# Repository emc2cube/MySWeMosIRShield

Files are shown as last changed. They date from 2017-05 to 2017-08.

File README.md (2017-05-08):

MySWeMosIRShield - IR blaster shield for WeMos D1 Mini with HTTP and MySensors support
==========

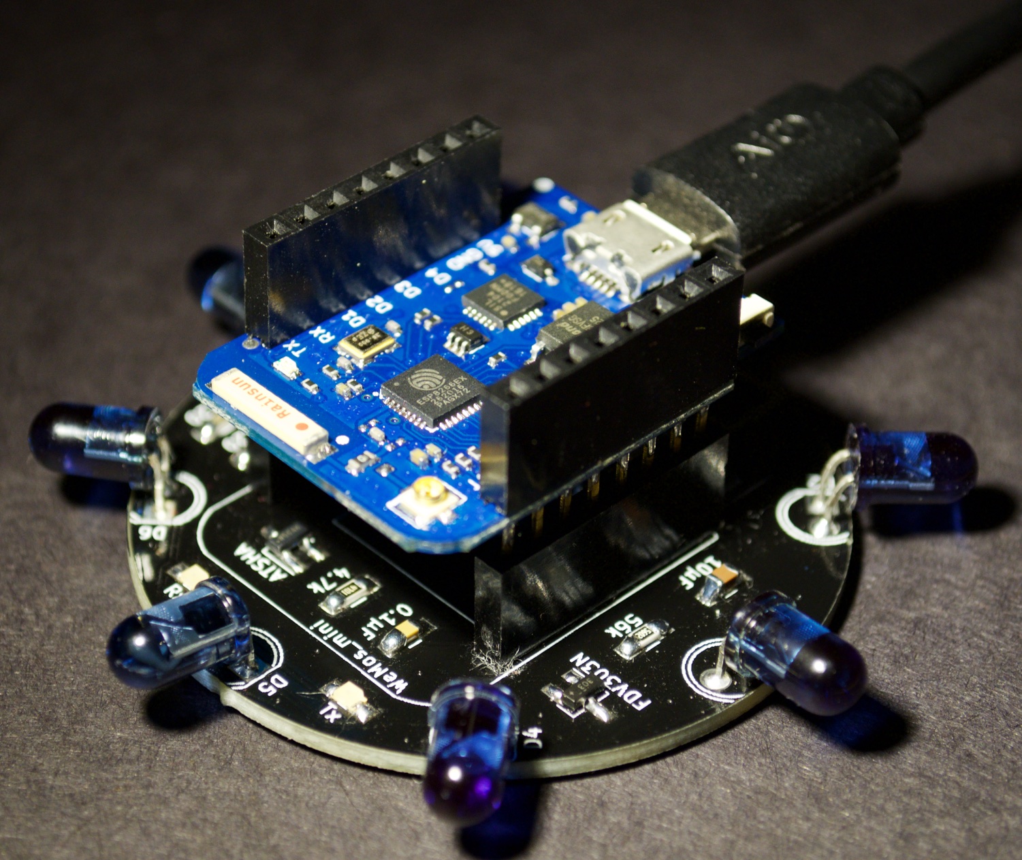
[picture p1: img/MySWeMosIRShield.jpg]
MySWeMosIRShield

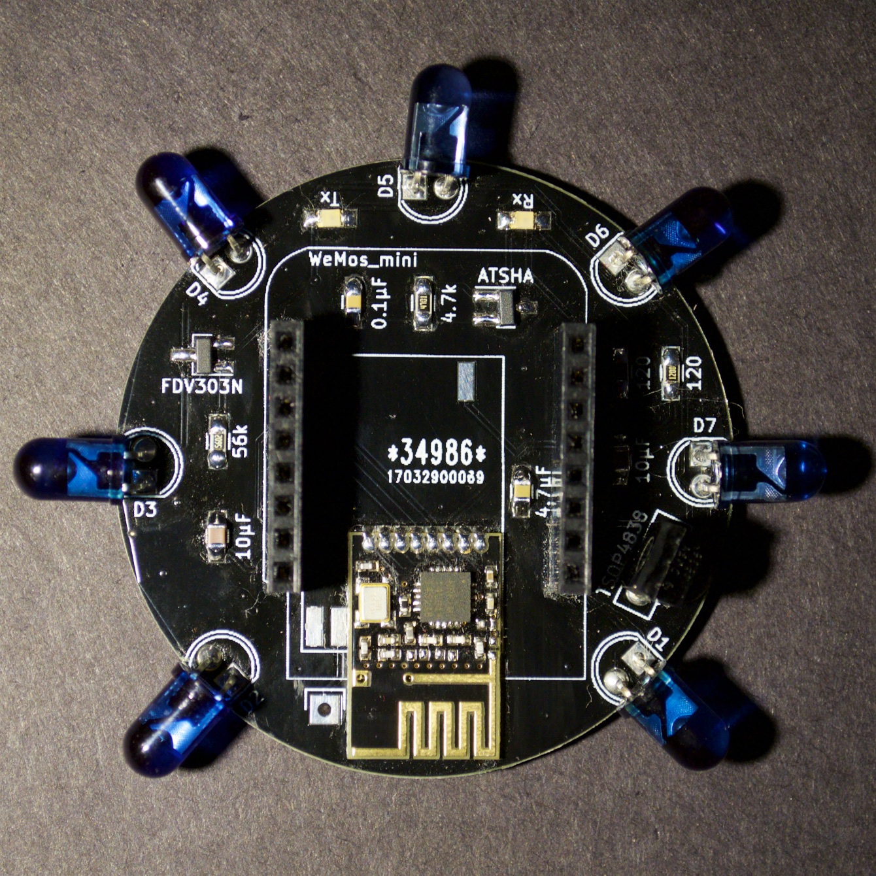
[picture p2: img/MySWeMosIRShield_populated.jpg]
MySWeMosIRShield populated board

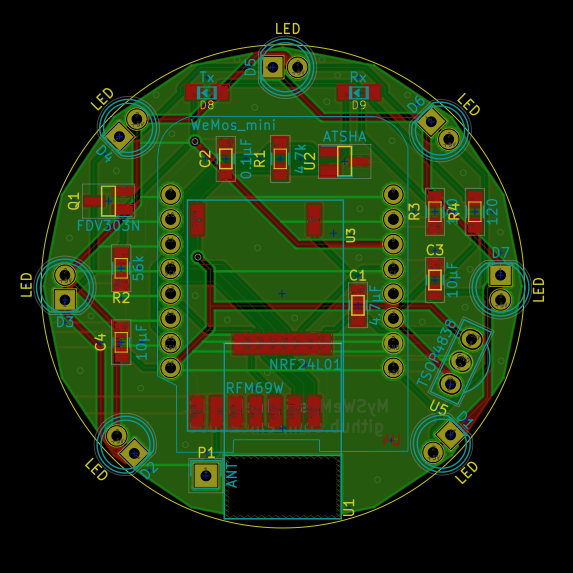
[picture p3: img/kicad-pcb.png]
KiCad view


Description
-----------

[MySensors](http://www.mysensors.org) [WeMos Mini](https://www.wemos.cc/product/d1-mini-pro.html) Infra-Red blaster and receiver shield with support for SMD NRF24L01+ or SMD RFM69(H)W radio modules.

Ordering
--------

Gerber files are included so you can order these PCB at your favorite PCB fab house and solder the few components yourself.
For an easy ordering process, you can directly order these PCB without having to do anything else:
- [PCBs.io](https://PCBs.io/share/zeBwV) 4 for $14.70, black 1.6mm PCB, ENIG finish, 2-3 weeks.
- [DirtyPCBs](http://dirtypcbs.com/store/designer/details/10880/3104/myswemosirshield) ~10 for $15.95, multiple colors and PCB thickness, HASL finish, 5-8 weeks.

Assembly
--------

Start by soldering all the SMD components, then proceed to WeMos header, IR LEDs and IR receiver.
By default, the BOM indicates TSAL6400 LEDs but you can use any high-power IR LEDs to have different beam angle or power according to your needs. I personally use a mix of TSAL6400, TSAL6200 and TSAL6100.
Some of the SMD 0805 capacitors are optional and could be skipped but I still recommended to solder all of them for optimal operation.

Optional components
-------------------

### Status LEDs
Tx and Rx LEDs are optional. Their only purpose is to indicate than an IR signal was either sent or received.
If you do not wish to add these status LEDs you can also skip both 120Ω SMD 0805 resistors.
By default, in the BOM Rx is green and Tx is yellow, but you can use different colors, update their corresponding current limiting resistor if needed.

### ATSHA204 module (unsupported?)
For security reasons, you can add a CryptAuthEE SHA256 chip. This will allow you to sign messages and will secure communications between the gateway and other nodes (this is not encryption, just signing).
If you decide to add the ATSHA204 chip you will need to add a 0.1µF SMD 0805 decoupling capacitor and 4.7kΩ SMD 0805 pull-up resistor.
Signing can also be done at the software level, without the chip if you decide to add this function later.
For complete reference see the detailed [MySensors Security & Signing guide](https://www.mysensors.org/about/signing)

### IR receiver (TSOP4838)
The Infra-Red module is optional, if you already know your IR codes or plan to learn them separately you can omit it.

### Radio module
Because this module is based on ESP8266 you do not necessary need to install a radio module.
- You can use it as an independent module, only using HTTP, internal timers or with any other program that do not need to communicate with a radio network.
- You can use it as a gateway, connecting your controller to the module by WiFi directly.

Installation
-------

Plug your [WeMos Mini](https://www.wemos.cc/product/d1-mini-pro.html) on top of the shield and power it through the micro USB port.
Do not forget to edit the various options of the [Arduino example code](https://github.com/emc2cube/MySWeMosIRShield/tree/master/Arduino/) before uploading it.

Arduino
-------

Included program

### MySWeMosIRShield-RoboVac_TV
Example code implementing custom web server and MySensors support.
You will (very probably) need to modify this code with your own IR codes and definitions.
This program was created to allow me to control my [Eufy RoboVac 11 robotic vacuum cleaner](http://amzn.to/2pbbndL) which unfortunately by default lack of any advanced scheduling options. By default, this vacuum cleaner will start its "auto" mode every day at the same hour, but can now be scheduled to operate only certain days, at different times, or even using different modes.

This program will set up a web server on your WeMos that you can access from any other device on your local network or by connecting directly to the ESP8266 hotspot (depending on WiFi settings) allowing you to trigger IR commands.
Interface is optimized for access through a smartphone, allowing you to use it as a smart remote.

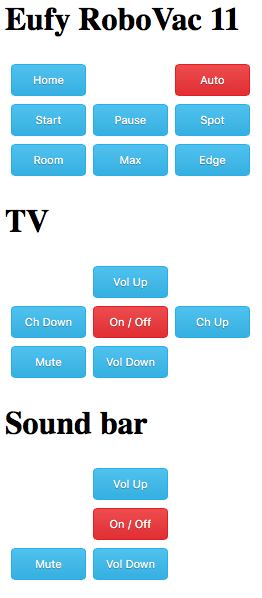
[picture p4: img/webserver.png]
WebServer


It will also create a [MySensors](http://www.mysensors.org) node behaving like a selector switch. You can then program it to perform various actions through your controller.

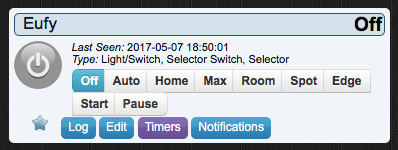
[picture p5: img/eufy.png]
Eufy


Revision history
----------------

Version 1.0: Initial release.

Special Kicad libraries
---------------

This project use the [Kicad footprints and templates for WeMos D1 mini board](https://github.com/jerome-labidurie/d1_mini_kicad) library.

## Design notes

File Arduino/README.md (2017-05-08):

MySWeMosIRShield - IR blaster shield for WeMos D1 Mini with HTTP and MySensors support
==========

Arduino
-------

Included program

### MySWeMosIRShield-RoboVac_TV
Example code implementing custom web server and MySensors support.
You will (very probably) need to modify this code with your own IR codes and definitions.
This program was created to allow me to control my [Eufy RoboVac 11 robotic vacuum cleaner](http://amzn.to/2pbbndL) which unfortunately by default lack of any advanced scheduling options. By default, this vacuum cleaner will start its "auto" mode every day at the same hour, but can now be scheduled to operate only certain days, at different times, or even using different modes.

This program will set up a web server on your WeMos that you can access from any other device on your local network or by connecting directly to the ESP8266 hotspot (depending on WiFi settings) allowing you to trigger IR commands.
Interface is optimized for access through a smartphone, allowing you to use it as a smart remote.

WebServer

It will also create a [MySensors](http://www.mysensors.org) node behaving like a selector switch. You can then program it to perform various actions through your controller.

Eufy

Improving the code
----------------

If you have a great program using this hardware feel free to contact me or push a commit to add other examples.
I have a few extra PCBs from previous iterations with some minor defects or missing features, if you have a working exemple on a breadboard I will happily send you one PCB for free to improve the code!

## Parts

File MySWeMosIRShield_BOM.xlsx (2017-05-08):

Quantity | Reference | Value | Package | Manufacturer | Manufacturer P/N | Mouser P/N | Comment | Aliexpress or Ebay link
1 | C1 | 4.7µF | SMD 0805 | Murata | GRM21BR61C475KA88K | 81-GRM21BR61C475KA8K |  | http://www.aliexpress.com/item/1LOT-100PCS-Chip-Capacitors-4-7uF-475K-16V-10-0805-Package0805-2012-Metric/32561376020.html
1 | C2 | 0.1µF | SMD 0805 | Murata | GRM21R71C104JA01D | 81-GRM21R71C104JA01D |  | http://www.aliexpress.com/item/1LOT-100PCS-Chip-Capacitors-0-1uF-104K-16V-10-0805-Package0805-2012-Metric/32560085454.html
2 | C3,C4 | 10µF | SMD 0805 | Murata | GRM21BR6YA106KE43L | 81-GRM21BR6YA106KE3L |  | https://www.aliexpress.com/item/1849449/32560458041.html
1 | R1 | 4.7k | SMD 0805 | Bourns | CR0805-JW-472ELF | 652-CR0805-JW-472ELF |  | http://www.aliexpress.com/item/100pcs-lot-SMD-Chip-Resistor-1-0805-4-7K-4700-OHMS-1-8W-100-YAGEO-New/32570155447.html
1 | R2 | 56k | SMD 0805 | Bourns | CR0805-JW-563ELF | 652-CR0805JW-563ELF |  | http://www.aliexpress.com/item/100pcs-lot-SMD-Chip-Resistor-1-0805-56K-1-8W-100-YAGEO-New-Original-Chip-Fixed/32570183133.html
2 | R3,R4 | 120 | SMD 0805 | Bourns | CR0805-FX-1200ELF | 652-CR0805FX-1200ELF
1 | U1 | NRF24L01 | NRF24L01-SMD | Radio module | NRF24L01+ SMD |  | U1 or U2 | https://www.aliexpress.com/item/5pcs-Free-Shipping-NRF24l01-2-4GHz-Wireless-Module-Mini-Version/32430542898.html
1 | U2 | ATSHA | SOT-23-3 | Atmel | ATSHA204A-STUCZ-T | 566-ATSHA204ASTUCZ-T | Optional, for signing
1 | U3 | RFM69W | RFM69(H)W-SMD | Radio module | RFM69(H)W SMD |  | U1 or U2 | https://www.aliexpress.com/item/New-RFM69HW-868Mhz-HopeRF-Wireless-Transceiver-RFM69HW-868S2-For-Remote-HM/32707574282.html
1 | U4 | WeMos_mini | WeMos D1 mini Pin Header | WeMos | D1 mini pro |  |  | https://www.aliexpress.com/item/WEMOS-D1-mini-Pro-16M-bytes-external-antenna-connector-ESP8266-WIFI-Internet-of-Things-development-board/32724692514.html
1 | U5 | TSOP4838 | Through Hole | Vishay Semiconductors | TSOP4838 | 782-TSOP4838 |  | https://www.aliexpress.com/item/2PCS-38-kHz-Remote-TSOP4838-DIP-3-Receiver-Infrared-Radiation-Module/32634580343.html
1 | Q1 | FDV303N | SOT-23-3 | Fairchild Semiconductor | FDV303N | 512-FDV303N |  | https://www.aliexpress.com/item/Free-shippin-10pcs-lot-FDV303N-SOT-23-new-original/32551535591.html
7 | D1-D7 | LED | Through Hole | Vishay Semiconductors | TSAL6400 | 782-TSAL6400 |  | https://www.aliexpress.com/item/10-PCS-LOT-TSAL6400-infrared-transmitting-tube/32766698010.html
1 | P1 | ANT | Through Hole | RFM69 antenna |  |  | Various frequencies
1 | D8 | Tx | SMD 0805 | OSRAM Opto Semiconductors | LG R971-KN-1 | 720-LGR971-KN-1 | Green | https://www.aliexpress.com/item/5-Colors-100Pcs-Lot-0805-SMD-LED-Kit-White-Red-Yellow-Green-Blue-Light-Emitting-Diode/32477664225.html
1 | D9 | Rx | SMD 0805 | OSRAM Opto Semiconductors | LY R976-PS-36 | 720-LYR976-PS-36 | Yellow | https://www.aliexpress.com/item/5-Colors-100Pcs-Lot-0805-SMD-LED-Kit-White-Red-Yellow-Green-Blue-Light-Emitting-Diode/32477664225.html

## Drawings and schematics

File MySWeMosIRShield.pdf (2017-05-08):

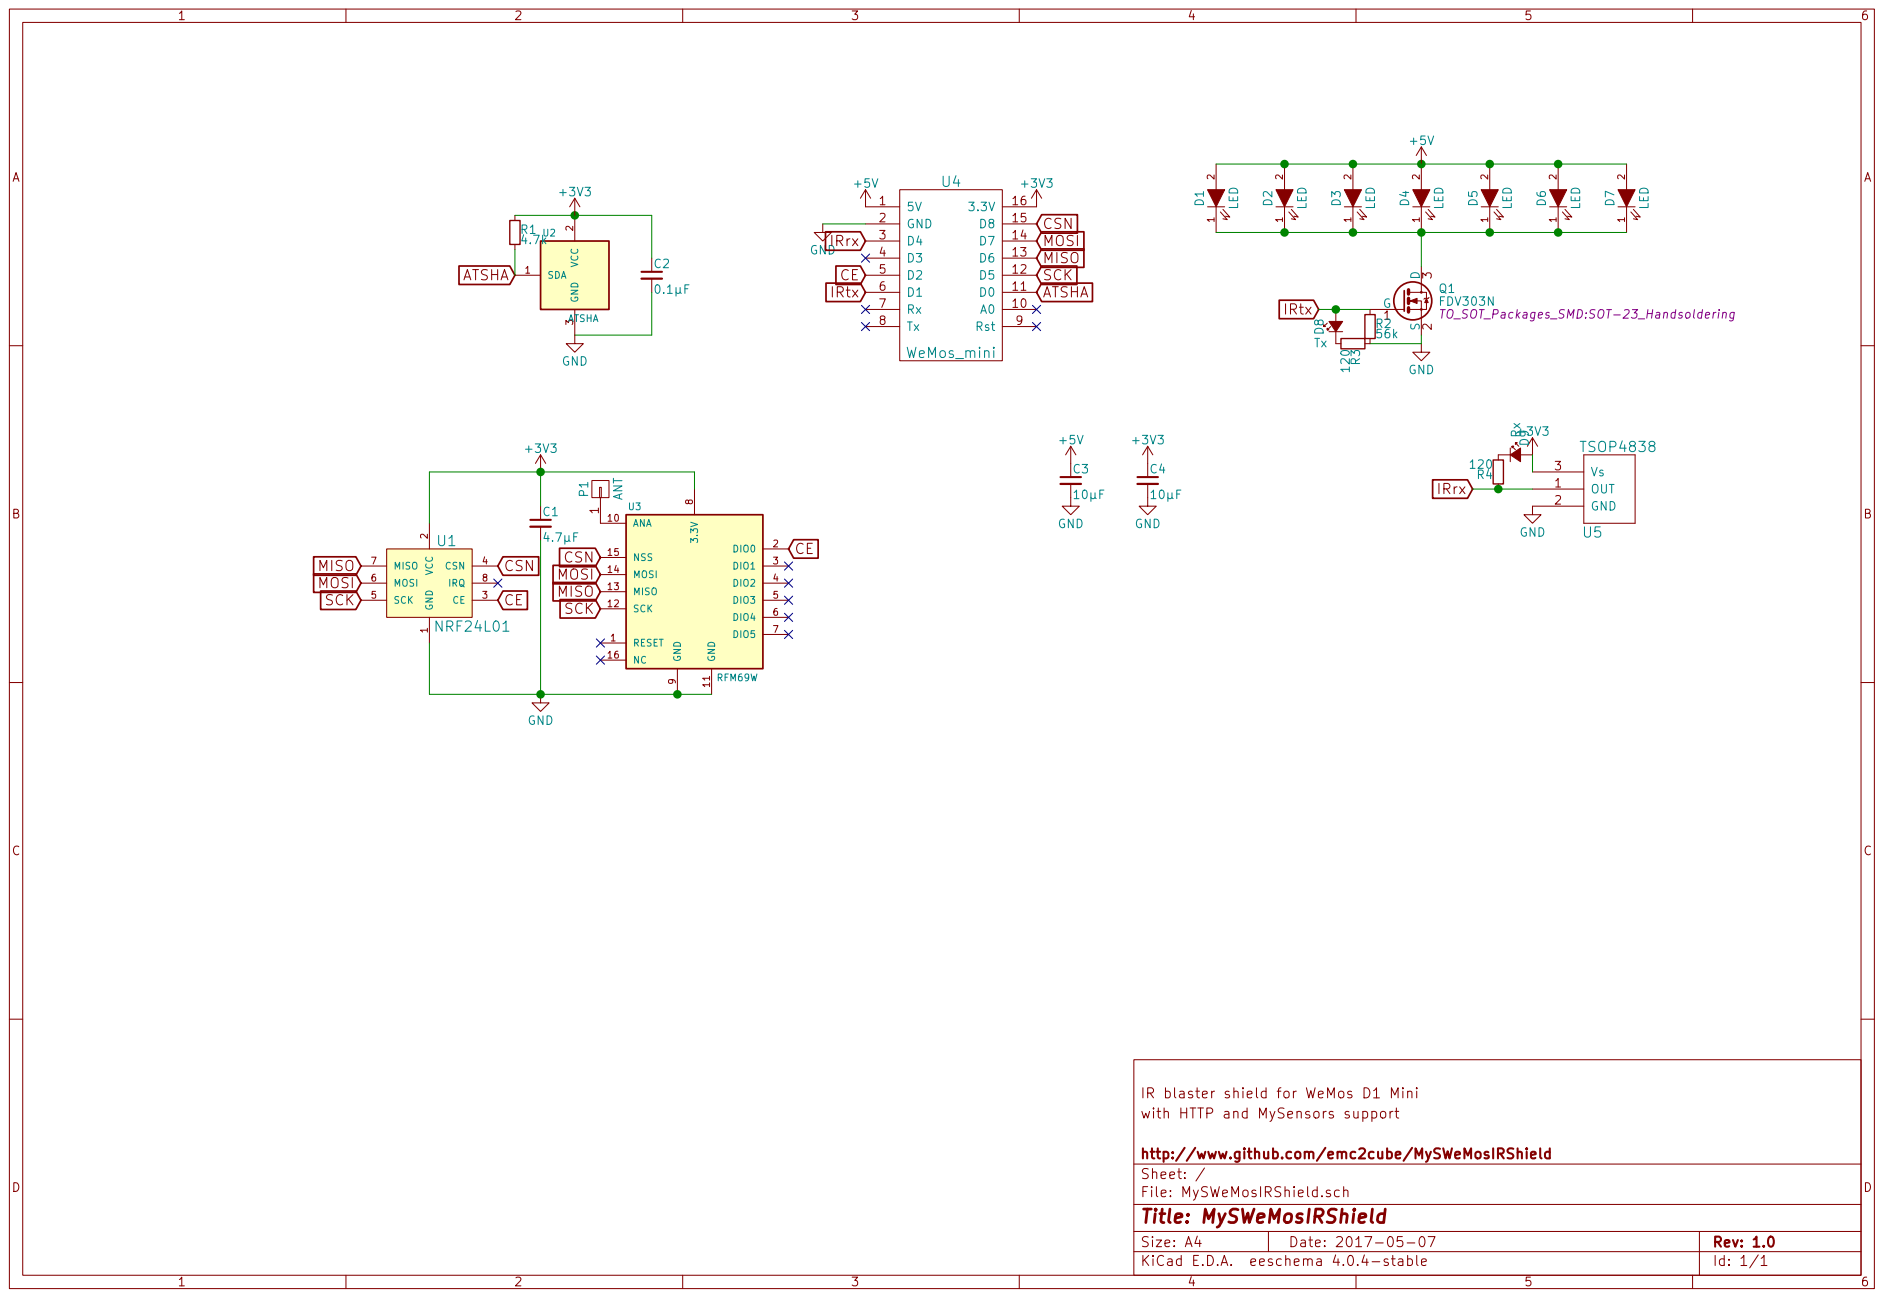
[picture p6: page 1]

9 ANA 10 GND 11 SCK 12 MISO 13 MOSI 14 NSS 15 NC 16 U3 RFM69W GND

2 CE 3 CSN 4 SCK 5 MOSI 6 MISO 7

IR blaster shield for WeMos D1 Mini
with HTTP and MySensors support

File: MySWeMosIRShield.sch Sheet: / http://www.github.com/emc2cube/MySWeMosIRShield

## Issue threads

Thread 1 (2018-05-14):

Can we add RF receiver and sensor module as well

rajkiranjeet, 2018-05-14:
Hi
Can we add RF receiver and sensor module as well ?
any update with pcb if u can ?

emc2cube, 2018-05-14:
RF receivers already present.

rajkiranjeet, 2018-05-18:
what is position on board ?

Closed 2018-05-14.

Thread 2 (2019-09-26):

Random inrfared values received from TSOP4838

0xC0DEBA5E, 2019-09-26:
I get a lot of random readings when I connect the TSOP4838 to my board.

Maybe it's because the pin of the blue LED on the board of the ESP8266 is the same the data pin of the TSOP4838 is connected to (D4).

I might have to mention that I didn't solder C1 onto the board, because I don't use the MySensors Board. So I'm not shure wether this comes from ripples in the supply voltage or if it is noise from the LED or something like that.

I removed the TSOP4838 and the random values were gone.

If I pull down D4 (with a wire to GND), the LED lights up and if i open/close the connection between D4 and GND, random values are received again.

According to the [WEMOS Wiki](https://wiki.wemos.cc/products:d1:d1_mini) the pin D4 is connected to the internal LED.

If this pin is used as output to set the internal LED, it probably shouldn't be used as input for the readings from the TSOP4838.

So my question is:

Is the data pin D4 on your board also connected to the internal LED of your ESP8266? The board from the pictures in README.md looks a little bit different than mine.

emc2cube, 2019-09-26:
Yes my board also have D4 connected to the internal LED. No issues on my side (but nothing in my program call for any blinking)

You may want to try to upload this to your wemos, changing the pin to D4, and see if with a simple program you have the same issue?
https://github.com/crankyoldgit/IRremoteESP8266/blob/master/examples/IRrecvDumpV2/IRrecvDumpV2.ino

Else maybe some defects on the board, honestly not idea.

0xC0DEBA5E, 2019-09-26:
My TSOP4838 was broken. I used another one and the problems were gone. I also tested other input pins with the broken TSOP4838 and got the same result. With the new one everything seems to work like it should.

Thank you very much for your help. I will close this issue now. But one should keep in mind, that blinking the internal LED will possibly break IR-Receiver functionality.

Closed 2019-09-26.

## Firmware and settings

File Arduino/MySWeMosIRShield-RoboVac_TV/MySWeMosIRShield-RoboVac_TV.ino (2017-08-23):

/**

   MySWeMosIRShield - IR blaster shield for WeMos D1 Mini with HTTP and MySensors support
   https://github.com/emc2cube/MySWeMosIRShield/

   Make sure to fill in your ssid and WiFi password below
   If you decide to enable ESP8266 OTA update it is recommended to set a password
   You will need to manually edit the IR codes in either/both the WebServer and MySensors section deep in the code

 *******************************

   The MySensors Arduino library handles the wireless radio link and protocol
   between your home built sensors/actuators and HA controller of choice.
   The sensors forms a self healing radio network with optional repeaters. Each
   repeater and gateway builds a routing tables in EEPROM which keeps track of the
   network topology allowing messages to be routed to nodes.

   Created by Henrik Ekblad <henrik.ekblad@mysensors.org>
   Copyright (C) 2013-2015 Sensnology AB
   Full contributor list: https://github.com/mysensors/Arduino/graphs/contributors

   Documentation: http://www.mysensors.org
   Support Forum: http://forum.mysensors.org

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
**/


// ** WiFi and network configuration **
// WiFi mode and configuration
// WIFI_STA       Connect to your WiFi network only
// WIFI_AP        Create and broadcast it's own WiFi network
// WIFI_AP_STA    Both
// WIFI_OFF       No WiFi
#define WIFI_MODE WIFI_STA

// WiFi credentials
const char *ssid = "YourSSIDHere";
const char *password = "YourPSKHere";

// Define password for OTA updates (recommended but optional)
//#define ESP8266_OTA_PASSWORD "MySuperSecretOTAPassword"


// ** MySensors Radio configuration **
// Enables and select radio type (if attached)
#define MY_RADIO_NRF24
//#define MY_RADIO_RFM69

// RF24 settings
// Use custom RF24 channel (default 76)
//#define MY_RF24_CHANNEL 42
// Enables RF24 encryption (all nodes and gateway must have this enabled, and all must be personalized with the same AES key)
//#define MY_RF24_ENABLE_ENCRYPTION

// RF69 settings
// RFM69 Frequency, default = 868MHz
//#define MY_RFM69_FREQUENCY RF69_868MHZ // RFM69 frequency to use (RF69_433MHZ for 433MHz, RF69_868MHZ for 868MHz or RF69_915MHZ for 915MHz)
// RFM69 Network ID. Use the same for all nodes that will talk to each other, default = 100
//#define MY_RFM69_NETWORKID     42
// Enables RFM69 encryption (all nodes and gateway must have this enabled, and all must be personalized with the same AES key)
//#define MY_RFM69_ENABLE_ENCRYPTION

// Enable this if you are running a RFM69HW module
//#define MY_IS_RFM69HW

// ** Mysensors additional functions **
// Use custom static node ID
// If disabled node ID will be automatically assigned
//#define MY_NODE_ID 42

// Use custom parent node ID. Use 0 to force direct connection to the gateway.
// If disabled parent ID will be automatically assigned
//#define MY_PARENT_NODE_ID 0

// Enable repeater feature for this node
//#define MY_REPEATER_FEATURE

// Enable software signing
//#define MY_SIGNING_SOFT

// Enable hardware signing
//#define MY_SIGNING_ATSHA204

// General signing settings
// Enable this if you want destination node to sign all messages sent to this gateway.
//#define MY_SIGNING_REQUEST_SIGNATURES
// Enable node whitelisting
//#define MY_SIGNING_NODE_WHITELISTING {{.nodeId = GATEWAY_ADDRESS,.serial = {0x09,0x08,0x07,0x06,0x05,0x04,0x03,0x02,0x01}}}

// Set how long to wait for radio transport to be ready. (in milliseconds)
#define MY_TRANSPORT_WAIT_READY_MS 10000

// Enable debug prints to serial monitor
//#define MY_DEBUG


// ** RAW IR codes **
uint16_t khz = 38; // 38kHz is the most common frequency
uint16_t eufyHOME[83] = {2950, 3000, 550, 450, 550, 1400, 550, 1450, 550, 450, 550, 1400, 550, 450, 550, 450, 550, 450, 550, 450, 500, 500, 450, 550, 500, 450, 550, 1450, 500, 1450, 550, 1450, 550, 1450, 500, 500, 500, 500, 550, 400, 550, 450, 550, 450, 500, 500, 500, 450, 550, 450, 450, 550, 500, 500, 500, 500, 550, 450, 500, 450, 550, 450, 500, 500, 550, 450, 500, 500, 550, 1400, 550, 1450, 500, 1450, 550, 450, 550, 1400, 500, 1500, 550, 1400, 550}; // UNKNOWN E8BEB62D
uint16_t eufyAUTO[83] = {2950, 3000, 550, 450, 550, 1450, 500, 1450, 550, 450, 550, 1400, 600, 400, 550, 450, 550, 450, 550, 1450, 500, 450, 550, 1450, 550, 450, 550, 450, 550, 450, 500, 450, 550, 450, 550, 450, 550, 450, 550, 450, 550, 450, 500, 450, 550, 450, 550, 450, 550, 400, 600, 400, 550, 450, 550, 450, 500, 500, 500, 500, 500, 450, 550, 450, 550, 450, 550, 450, 550, 450, 550, 450, 500, 450, 550, 1450, 550, 450, 550, 450, 550, 450, 500}; // UNKNOWN E474C5C6
uint16_t eufySTART[83] = {3000, 3050, 550, 500, 550, 1500, 550, 1500, 550, 500, 550, 1450, 600, 450, 600, 450, 600, 450, 600, 1450, 500, 1550, 550, 1500, 550, 1500, 550, 500, 550, 1500, 550, 500, 550, 1450, 600, 450, 600, 450, 600, 450, 550, 500, 500, 550, 500, 550, 550, 500, 550, 500, 550, 500, 550, 500, 550, 500, 550, 500, 550, 500, 550, 500, 550, 500, 550, 500, 550, 500, 550, 1500, 550, 450, 600, 1450, 600, 1450, 550, 1500, 550, 500, 550, 1500, 550}; // UNKNOWN C1C301C7
uint16_t eufyPAUSE[83] = {3050, 3000, 600, 450, 600, 1450, 600, 1450, 600, 500, 550, 1500, 600, 450, 550, 500, 600, 450, 600, 1450, 550, 1450, 600, 1450, 600, 1450, 600, 500, 550, 450, 600, 450, 600, 450, 600, 500, 550, 450, 600, 500, 550, 450, 600, 450, 600, 450, 550, 500, 550, 500, 550, 500, 550, 500, 600, 450, 550, 500, 600, 500, 550, 500, 550, 500, 550, 500, 550, 500, 600, 1500, 550, 450, 600, 1500, 550, 1500, 600, 450, 550, 500, 550, 450, 600}; // UNKNOWN 25638DD6
uint16_t eufySPOT[83] = {3000, 2950, 550, 500, 500, 1450, 550, 1450, 500, 500, 500, 1450, 550, 450, 550, 450, 550, 450, 500, 500, 500, 450, 450, 550, 550, 1400, 600, 450, 500, 500, 500, 1450, 550, 450, 500, 500, 500, 500, 500, 500, 500, 450, 550, 450, 500, 500, 550, 400, 600, 400, 550, 450, 550, 450, 500, 500, 500, 500, 450, 500, 550, 450, 500, 450, 550, 450, 550, 450, 550, 1450, 550, 1400, 550, 1450, 550, 1400, 600, 450, 500, 1450, 500, 500, 450}; // UNKNOWN ED40C288
uint16_t eufyROOM[83] = {2950, 3000, 550, 400, 600, 1400, 550, 1450, 550, 450, 550, 1400, 600, 400, 550, 450, 550, 400, 550, 450, 550, 450, 500, 1500, 500, 1450, 550, 450, 600, 1400, 550, 450, 550, 450, 550, 400, 550, 450, 600, 400, 550, 450, 550, 400, 600, 400, 550, 450, 550, 450, 550, 450, 500, 500, 450, 500, 550, 450, 550, 450, 550, 450, 550, 450, 550, 450, 550, 1400, 550, 450, 550, 450, 550, 1450, 550, 1400, 550, 1400, 600, 400, 500, 500, 550}; // UNKNOWN 1A8F2EB8
uint16_t eufyEDGE[83] = {2950, 3000, 550, 450, 500, 1450, 550, 1450, 550, 450, 550, 1400, 550, 450, 550, 450, 550, 450, 550, 400, 550, 450, 500, 1500, 550, 450, 500, 500, 500, 450, 550, 1450, 550, 1450, 550, 450, 500, 500, 500, 450, 550, 450, 550, 450, 550, 400, 600, 400, 550, 450, 550, 450, 500, 500, 450, 550, 500, 450, 550, 450, 550, 450, 550, 450, 550, 450, 550, 1450, 500, 450, 550, 450, 550, 450, 550, 1450, 500, 500, 500, 1450, 550, 1400, 550}; // UNKNOWN FFB2DFB1
uint16_t eufyMAX[83] = {3000, 2950, 600, 400, 550, 1450, 550, 1450, 500, 450, 550, 1450, 550, 400, 600, 400, 550, 450, 550, 450, 500, 500, 450, 500, 550, 1450, 550, 450, 550, 450, 550, 1400, 550, 1450, 550, 450, 550, 450, 550, 450, 550, 400, 550, 450, 550, 450, 550, 400, 550, 450, 550, 450, 550, 450, 450, 550, 500, 450, 550, 450, 600, 400, 550, 450, 550, 450, 550, 450, 550, 1400, 550, 1450, 550, 1400, 550, 1450, 550, 450, 550, 1400, 550, 1450, 550}; // UNKNOWN A2B091CB


// ******************************************//
// You probably don't need to edit this part //
// ******************************************//

#include <EEPROM.h>
#include <SPI.h>
#include <WiFiClient.h>
#include <ESP8266WebServer.h>
#include <ESP8266mDNS.h>
#include <ArduinoOTA.h>
extern "C" {
#include "user_interface.h"
}
#include <IRremoteESP8266.h>  // From https://github.com/markszabo/IRremoteESP8266/
#include <IRsend.h>  // Needed if you want to send IR commands.
#include <IRrecv.h>  // Needed if you want to receive IR commands.
#include <IRutils.h>

// MySensors
#define SN "MySWeMosIRShield"   // Name of the sketch
#define SV "2.1.1"              // Version (2.x : compiled with MySensors 2.x)
boolean metric = true;          // Use SI by default
#define MESSAGEWAIT 500         // Wait a few ms between radio Tx
#define CHILD_ID_TxLED 0
#define CHILD_ID_RxLED 1

// Signing settings
#define MY_SIGNING_SOFT_RANDOMSEED_PIN A0
#define MY_SIGNING_ATSHA204_PIN D0  // GPIO 16

// Enable signing related debug prints to serial monitor if debug and signing are both enabled
#if ((defined MY_DEBUG) && ( defined MY_SIGNING_SOFT || defined MY_SIGNING_ATSHA204))
#define MY_DEBUG_VERBOSE_SIGNING
#endif

// Define RFM69 pins to match PCB traces
#if defined MY_RADIO_RFM69
#define MY_RF69_IRQ_PIN D2  // GPIO 4
#define MY_RF69_IRQ_NUM D2  // GPIO 4
#define MY_RF69_SPI_CS  D8  // GPIO 15
#endif

#define ARDUINO_ARCH_ESP8266

#include <MySensors.h>

// Define IR pins
uint16_t TX_PIN = D1; //an IR LED is connected to D1
uint16_t RX_PIN = D4; //an IR detector/demodulator is connected to D4
IRsend irsend(TX_PIN);
IRrecv irrecv(RX_PIN);

// IR decoding (from IRremoteESP8266: IRrecvDumpV2)
decode_results results; // Somewhere to store the results
irparams_t save;        // A place to copy the interrupt state while decoding.

// Setup AP IP Address
IPAddress ip(10, 0, 3, 1);
IPAddress gateway(10, 0, 3, 1);
IPAddress subnet(255, 255, 255, 0);

// WebServer configuration
ESP8266WebServer server(80);

// ******************************************//
// WebServer settings, you will need to edit //
// ******************************************//
void handleRoot() {
  server.send(200, "text/html", "\
<html>\
<head>\
  <title>MySWeMosIRShield: IR Remote</title>\
  <meta name=\"viewport\" content=\"initial-scale=1\">\
<style>\
  .bluebutton {\
  border: 1px solid #15aeec;\
  background-color: #49c0f0;\
  background-image: -webkit-linear-gradient(top, #49c0f0, #2cafe3);\
  background-image: linear-gradient(to bottom, #49c0f0, #2cafe3);\
  border-radius: 4px;\
  color: #fff;\
  line-height: 25px;\
  width: 75px;\
  transition: none;\
  text-shadow: 0 1px 1px rgba(0, 0, 0, .3);\
  text-align: center;\
}\
.bluebutton:hover {\
  border:1px solid #1090c3;\
  background-color: #1ab0ec;\
  background-image: -webkit-linear-gradient(top, #1ab0ec, #1a92c2);\
  background-image: linear-gradient(to bottom, #1ab0ec, #1a92c2);\
}\
.bluebutton:active {\
  background: #1a92c2;\
  box-shadow: inset 0 3px 5px rgba(0, 0, 0, .2);\
  color: #1679a1;\
  text-shadow: 0 1px 1px rgba(255, 255, 255, .5);\
}\
.redbutton {\
  border: 1px solid #eb1515;\
  background-color: #f04a4a;\
  background-image: -webkit-linear-gradient(top, #f04a4a, #e32d2d);\
  background-image: linear-gradient(to bottom, #f04a4a, #e32d2d);\
  border-radius: 4px;\
  color: #fff;\
  line-height: 25px;\
  width: 75px;\
  transition: none;\
  text-shadow: 0 1px 1px rgba(0, 0, 0, .3);\
  text-align: center;\
}\
.redbutton:hover {\
  border:1px solid #c21111;\
  background-color: #eb1d1d;\
  background-image: -webkit-linear-gradient(top, #eb1d1d, #c21b1b);\
  background-image: linear-gradient(to bottom, #eb1d1d, #c21b1b);\
}\
.redbutton:active {\
  background: #e32d2d;\
  box-shadow: inset 0 3px 5px rgba(0, 0, 0, .2);\
  color: #a11717;\
  text-shadow: 0 1px 1px rgba(255, 255, 255, .5);\
}\
table, th, td {\
    border-spacing: 5px 2px;\
    border: none;\
}\
</style> \
</head>\
<body>\
<h1>\
  Eufy RoboVac 11 \
</h1>\
<table>\
  <tr>\
    <td><a href=\"ir?eufy=home\"><button class=\"bluebutton\">Home</button></a></td>\
    <td></td>\
    <td><a href=\"ir?eufy=auto\"><button class=\"redbutton\">Auto</button></a></td>\
  </tr>\
  <tr>\
    <td><a href=\"ir?eufy=start\"><button class=\"bluebutton\">Start</button></a></td>\
    <td><a href=\"ir?eufy=pause\"><button class=\"bluebutton\">Pause</button></a></td>\
    <td><a href=\"ir?eufy=spot\"><button class=\"bluebutton\">Spot</button></a></td>\
  </tr>\
  <tr>\
    <td><a href=\"ir?eufy=room\"><button class=\"bluebutton\">Room</button></a></td>\
    <td><a href=\"ir?eufy=max\"><button class=\"bluebutton\">Max</button></a></td>\
    <td><a href=\"ir?eufy=edge\"><button class=\"bluebutton\">Edge</button></a></td>\
  </tr>\
</table>\
<h1>\
  TV \
</h1>\
<table>\
  <tr>\
    <td></td>\
    <td><a href=\"ir?tv=vup\"><button class=\"bluebutton\">Vol Up</button></a></td>\
    <td></td>\
  </tr>\
  <tr>\
    <td><a href=\"ir?tv=chdown\"><button class=\"bluebutton\">Ch Down</button></a></td>\
    <td><a href=\"ir?tv=power\"><button class=\"redbutton\">On / Off</button></a></td>\
    <td><a href=\"ir?tv=chup\"><button class=\"bluebutton\">Ch Up</button></a></td>\
  </tr>\
  <tr>\
    <td><a href=\"ir?tv=mute\"><button class=\"bluebutton\">Mute</button></a></td>\
    <td><a href=\"ir?tv=vdown\"><button class=\"bluebutton\">Vol Down</button></a></td>\
    <td></td>\
  </tr>\
</table>\
<h1>\
  Sound bar \
</h1>\
<table>\
  <tr>\
    <td></td>\
    <td><a href=\"ir?audio=vup\"><button class=\"bluebutton\">Vol Up</button></a></td>\
    <td></td>\
  </tr>\
  <tr>\
    <td></td>\
    <td><a href=\"ir?audio=power\"><button class=\"redbutton\">On / Off</button></a></td>\
    <td></td>\
  </tr>\
  <tr>\
    <td><a href=\"ir?audio=mute\"><button class=\"bluebutton\">Mute</button></a></td>\
    <td><a href=\"ir?audio=vdown\"><button class=\"bluebutton\">Vol Down</button></a></td>\
    <td></td>\
  </tr>\
</table>\
</body>\
</html>");
}

// ******************************************//
//  IR code settings, you will need to edit  //
// ******************************************//
void handleIr() {
  irrecv.disableIRIn();
  for (uint8_t i = 0; i < server.args(); i++) {
    if (server.argName(i) == "eufy")
    {
      if (server.arg(i) == "auto") { // Auto cleaning mode
        irsend.sendRaw(eufyAUTO, sizeof(eufyAUTO) / sizeof(eufyAUTO[0]), khz);
      }
      if (server.arg(i) == "home") { // Back to charging dock
        irsend.sendRaw(eufyHOME, sizeof(eufyHOME) / sizeof(eufyHOME[0]), khz);
      }
      if (server.arg(i) == "max") { // Max power
        irsend.sendRaw(eufyMAX, sizeof(eufyMAX) / sizeof(eufyMAX[0]), khz);
      }
      if (server.arg(i) == "spot") { // Spot cleaning mode
        irsend.sendRaw(eufySPOT, sizeof(eufySPOT) / sizeof(eufySPOT[0]), khz);
      }
      if (server.arg(i) == "edge") { // Edge cleaning mode
        irsend.sendRaw(eufyEDGE, sizeof(eufyEDGE) / sizeof(eufyEDGE[0]), khz);
      }
      if (server.arg(i) == "room") { // Single room cleaning mode
        irsend.sendRaw(eufyROOM, sizeof(eufyROOM) / sizeof(eufyROOM[0]), khz);
      }
      if (server.arg(i) == "start") { // Start
        irsend.sendRaw(eufySTART, sizeof(eufySTART) / sizeof(eufySTART[0]), khz);
      }
      if (server.arg(i) == "pause") { // Pause
        irsend.sendRaw(eufyPAUSE, sizeof(eufyPAUSE) / sizeof(eufyPAUSE[0]), khz);
      }
    }
    else if (server.argName(i) == "tv")
    {
      if (server.arg(i) == "power") { // switch On / Off
        irsend.sendNEC(0x20DF10EF, 32);
      }
      if (server.arg(i) == "chup") { // channel up
        irsend.sendNEC(0x20DF00FF, 32);
      }
      if (server.arg(i) == "chdown") { // channel down
        irsend.sendNEC(0x20DF807F, 32);
      }
      if (server.arg(i) == "vup") { // volume up
        irsend.sendNEC(0x20DF40BF, 32);
      }
      if (server.arg(i) == "vdown") { // volume down
        irsend.sendNEC(0x20DFC03F, 32);
      }
      if (server.arg(i) == "mute") { // mute
        irsend.sendNEC(0x20DF906F, 32);
      }
    }
    else if (server.argName(i) == "audio")
    {
      if (server.arg(i) == "power") { // switch On / Off
        irsend.sendRC6(0x150C, 20);
      }
      if (server.arg(i) == "vup") { // volume up
        irsend.sendRC6(0x1010, 20);
      }
      if (server.arg(i) == "vdown") { // volume down
        irsend.sendRC6(0x1011, 20);
      }
      if (server.arg(i) == "mute") { // mute
        irsend.sendRC6(0x100D, 20);
      }
    }
  }
  irrecv.enableIRIn();
  handleRoot();
}

void handleNotFound() {
  String message = "File Not Found\n\n";
  message += "URI: ";
  message += server.uri();
  message += "\nMethod: ";
  message += (server.method() == HTTP_GET) ? "GET" : "POST";
  message += "\nArguments: ";
  message += server.args();
  message += "\n";
  for (uint8_t i = 0; i < server.args(); i++) {
    message += " " + server.argName(i) + ": " + server.arg(i) + "\n";
  }
  server.send(404, "text/plain", message);
}
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
void loop() {
  // WebServer
  server.handleClient();

  // Arduino ESP8266 OTA
  ArduinoOTA.handle();

  // IR decoding (from IRremoteESP8266: IRrecvDumpV2)
  // Check if the IR code has been received.
  if (irrecv.decode(&results, &save)) {
    dumpInfo(&results);           // Output the results
    dumpRaw(&results);            // Output the results in RAW format
    dumpCode(&results);           // Output the results as source code
    Serial.println("");           // Blank line between entries
  }
  // End IR decoding
}

void receive(const MyMessage &message) {

  if (message.isAck()) {
#if defined MY_DEBUG
    Serial.println("ACK received");
#endif
  }

  int ID = message.sensor;
  int mySwitch = 0 ;
#if defined MY_DEBUG
  Serial.print("Sensor: ");
  Serial.println(ID);
#endif
  switch (ID) {                                           // If different sensors for this node
    case CHILD_ID_TxLED:                                  // The number of the V_PERCENTAGE sensor to be controlled
      if (message.type == V_PERCENTAGE) {                 // Percentage indicates the pattern
        mySwitch = map(message.getInt(), 0, 100, 0, 15);  // Map dimmer values to Switch states 0..9  and wrap
        irrecv.disableIRIn();
        // ******************************************//
        //  IR code settings, you will need to edit  //
        // ******************************************//
        switch (mySwitch) {
          case 0:
            {
#if defined MY_DEBUG
              Serial.println(F("OFF"));
#endif
            } // whatever on switch action 0
            break ;
          case 1:
            {
#if defined MY_DEBUG
              Serial.println("Sending eufyAUTO");
#endif
              irsend.sendRaw(eufyAUTO, sizeof(eufyAUTO) / sizeof(eufyAUTO[0]), khz);
            } // whatever on switch action 1
            break ;
          case 2:
            {
#if defined MY_DEBUG
              Serial.println(F("Sending eufyHome"));
#endif
              irsend.sendRaw(eufyHOME, sizeof(eufyHOME) / sizeof(eufyHOME[0]), khz);
            } // whatever on switch action 2
            break ;
          case 3:
            {
#if defined MY_DEBUG
              Serial.println(F("Sending eufyMAX"));
#endif
              irsend.sendRaw(eufyMAX, sizeof(eufyMAX) / sizeof(eufyMAX[0]), khz);
            } // whatever on switch action 3
            break ;
          case 4:
            {
#if defined MY_DEBUG
              Serial.println(F("Sending eufyROOM"));
#endif
              irsend.sendRaw(eufyROOM, sizeof(eufyROOM) / sizeof(eufyROOM[0]), khz);
            } // whatever on switch action 4
            break ;
          case 5:
            {
#if defined MY_DEBUG
              Serial.println(F("Sending eufySPOT"));
#endif
              irsend.sendRaw(eufySPOT, sizeof(eufySPOT) / sizeof(eufySPOT[0]), khz);
            } // whatever on switch action 5
            break ;
          case 6:
            {
#if defined MY_DEBUG
              Serial.println(F("Sending eufyEDGE"));
#endif
              irsend.sendRaw(eufyEDGE, sizeof(eufyEDGE) / sizeof(eufyEDGE[0]), khz);
            } // whatever on switch action 6
            break ;
          case 7:
            {
#if defined MY_DEBUG
              Serial.println(F("Sending eufySTART"));
#endif
              irsend.sendRaw(eufySTART, sizeof(eufySTART) / sizeof(eufySTART[0]), khz);
            } // whatever on switch action 7
            break ;
          case 8:
            {
#if defined MY_DEBUG
              Serial.println(F("Sending eufyPAUSE"));
#endif
              irsend.sendRaw(eufyPAUSE, sizeof(eufyPAUSE) / sizeof(eufyPAUSE[0]), khz);
            } // whatever on switch action 8
            break ;
          case 9:
            {
              // whatever on switch action 9
            }
            break ;
          case 10:
            {
              // whatever on switch action 10
            }
            break ;
            // max switch actions in Domoticz = 10
        }
        irrecv.enableIRIn();
        break ;
      }
  }
}

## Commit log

2017-05-08 Initial release
    Initial release
    [MySWeMosIRShield-B.Cu.gbl, MySWeMosIRShield-B.Mask.gbs, MySWeMosIRShield-B.SilkS.gbo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]
2025-07-02 Restructure firmware, add ESPHome config and docs
    Moved Arduino firmware and README into a new Firmware directory. Added ESPHome configuration (myswemosirshield.yaml) for Home Assistant integration and updated documentation to reflect ESPHome suppor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

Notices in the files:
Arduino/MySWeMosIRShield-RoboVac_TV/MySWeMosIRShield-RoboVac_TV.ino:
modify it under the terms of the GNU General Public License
